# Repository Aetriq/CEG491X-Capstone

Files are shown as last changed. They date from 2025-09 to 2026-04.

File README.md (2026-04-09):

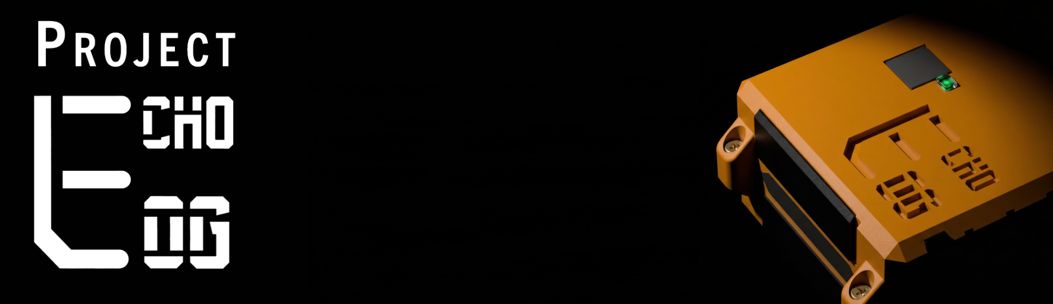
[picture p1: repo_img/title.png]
titlecard


<h1 align="center">Project EchoLog</h1>

<p align="center">
  CEG491X Capstone Project <br/>
  Faculty of Electrical and Computer Engineering @ University of Ottawa
  <br/>
  <br />

  <p align="center">
    
    &nbsp;
    
    &nbsp;
    
    &nbsp;
    
    &nbsp;
    
  <p align="center">

## Project Description
Based on the needs of our client, EchoLog is designed to be applicable with similar goals of recording and storing different forms of logs in high intensity/stress environments. It can also can provide value to any party from individuals that are spending out of pocket to improve their volunteering experience, to organizations with varying budgets. 

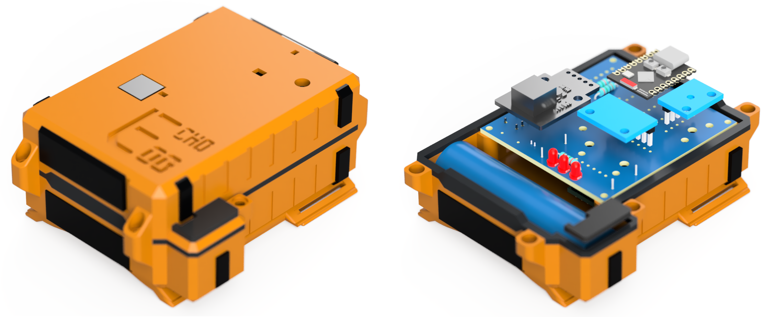
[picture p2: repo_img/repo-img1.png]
Concept Image Render

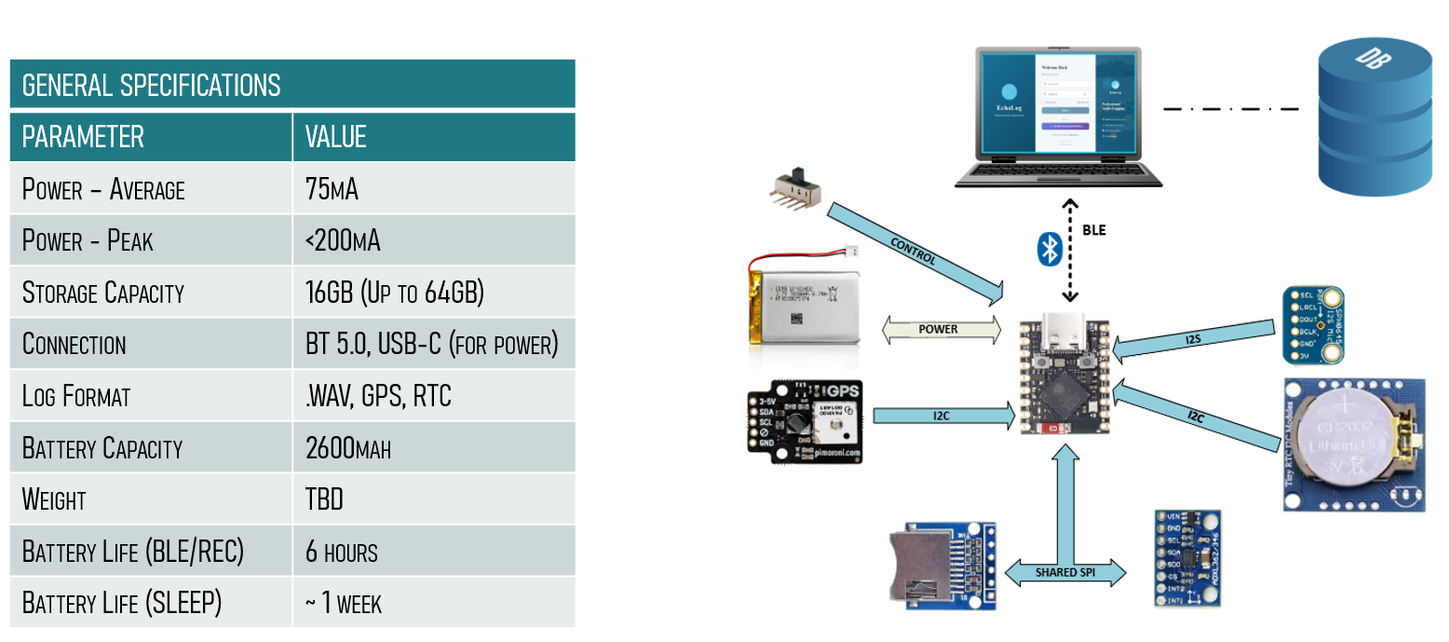
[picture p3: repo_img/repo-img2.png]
Specifications


## Development Images
<p align="center">
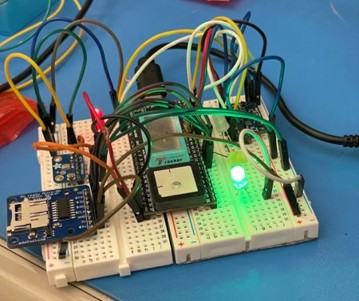
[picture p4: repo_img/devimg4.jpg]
devimg
  
</p>
<p align="center">
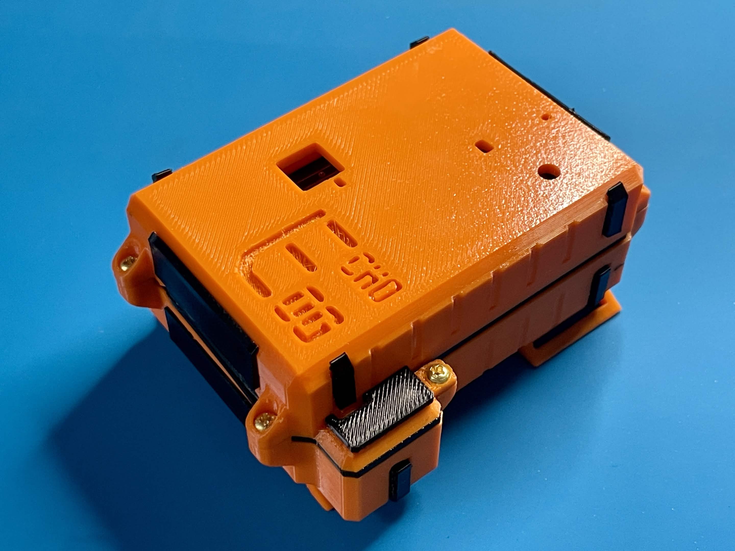
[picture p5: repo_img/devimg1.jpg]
devimg
  
</p>
<p align="center">
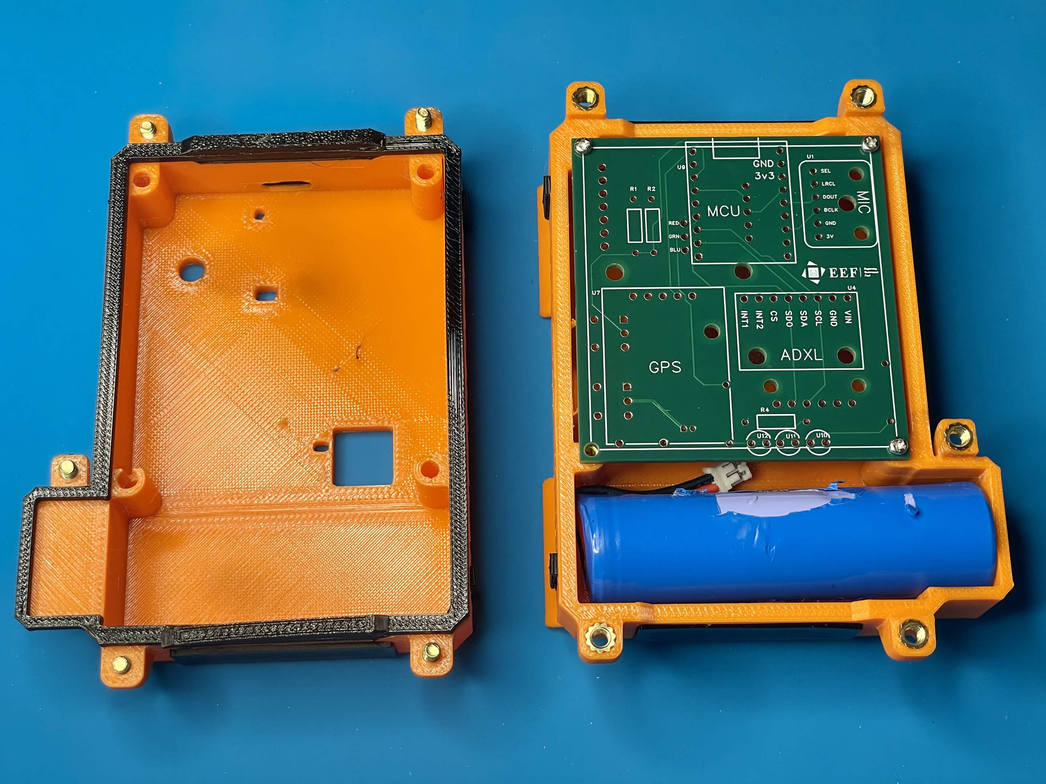
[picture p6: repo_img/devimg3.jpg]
devimg
  
</p>
<p align="center">
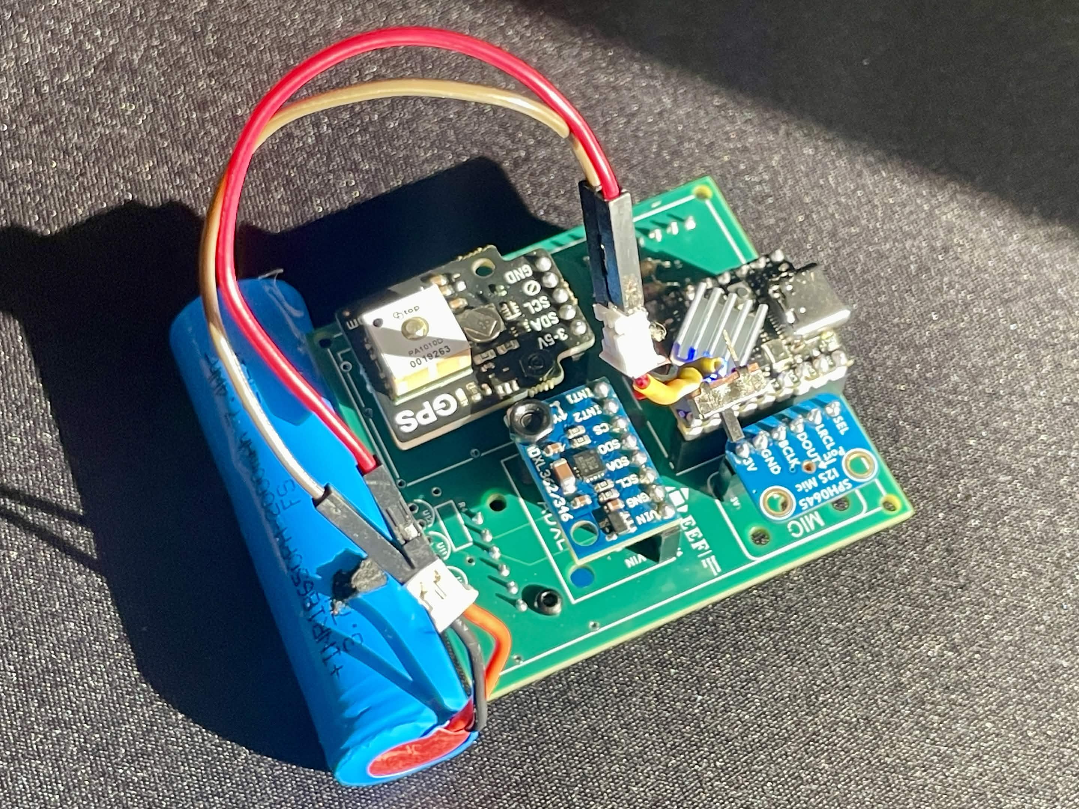
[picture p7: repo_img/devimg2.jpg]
devimg
  
</p>

---

## Features
- Fully handsfree operation & usage.
- Extremely low maitenance & high durability/physical protection.
- Rated for IP56 water/dust protection.
- Capable of sustaining external thermal loads up to 80C.
- Ultra low power, consuming <200mA peak, allowing for at least 8 hours of battery life. 
- Advanced gesture detection and fully autonomous recording of various formats, including audio and GPS.
- Dedicated app allows connection via USB-C serial and Bluetooth.

---

## Technologies Used
- **Frontend**: Angular, HTML, CSS.
- **Backend**: C, ESP-IDF Framework, Baremetal FreeRTOS
- **Image builder/flasher**: PlatformIO.

---
## Credits
- [Get your project supported with the the Engineering Endowment Fund (EEF)](https://www.uottawa.ca/faculty-engineering/student-hub/funding-student-initiatives)
- [ESP32-S3 by EspressIF](https://docs.espressif.com/projects/esp-idf/en/stable/esp32s3/)
- [EasyEDA](https://easyeda.com/)
- [AutoDesk Fusion](https://www.autodesk.com/products/fusion-360)

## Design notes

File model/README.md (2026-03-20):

<!-- PROJECT LOGO -->
<p align="center">
  <a href="https://github.com/Aetriq/CEG491X-Capstone">
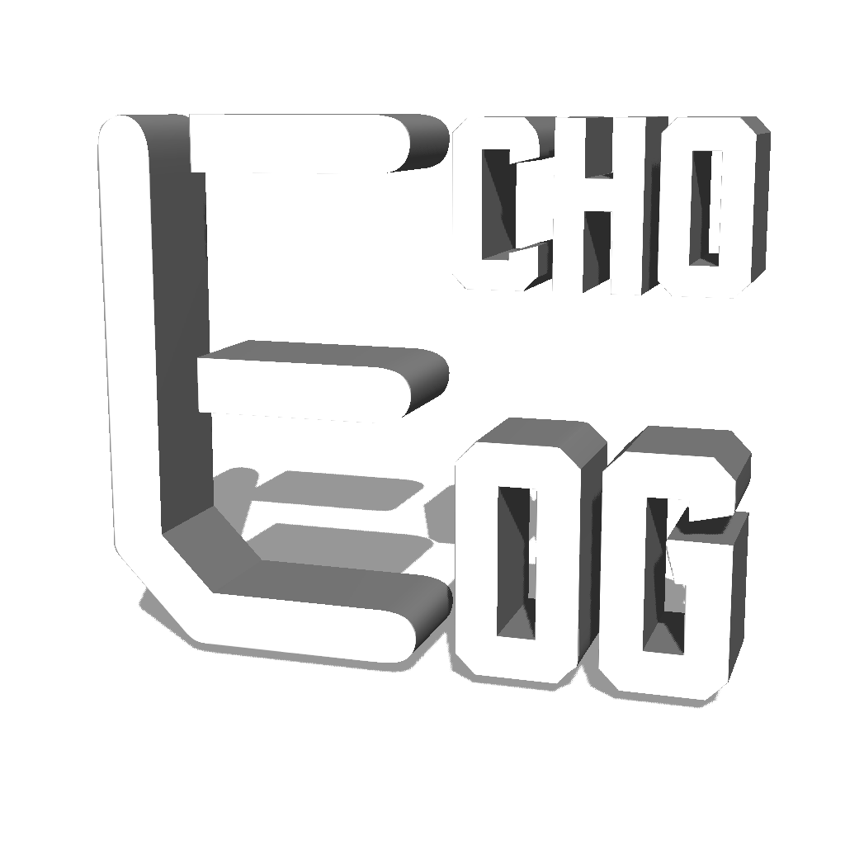
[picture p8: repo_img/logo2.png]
Project Logo
    
  </a>
</p>

<h1 align="center">Project EchoLog</h1>

<p align="center">
  CEG491X Capstone Project <br/>
  Faculty of Electrical and Computer Engineering @   University of Ottawa
  <br/>

  # Physical CAD Design for EchoLog 
<p align="center">
   
The following print settings are recommended and universal for all printers. All parts can be printed at once. This table uses the filament provided in the BOM (**Overture PETG**); other brands may vary in temperature. Warping may be eliminated by using a draft shield.

### Basic Printing Config

| Property | Ideal | Minimum |
| :--- | :--- | :--- |
| **Layer Height** | 0.15 – 0.2mm | 0.25 – 0.3mm |
| **Infill** | 35%, Gyroid | 10%, Gyroid |
| **Perimeter** | 5 | 3 |
| **Support** | Organic, build plate only | Snug, build plate only |
| **Speed** | 200 – 600mm/s | 25 – 100mm/s |
| **Temperature** | 240°C, 80°C bed | 230°C, 70°C bed |

---

The following advanced print settings are also recommended but limited to the **Overture PET-G** [filament](https://a.co/d/02w19UyD) for reference. These properties were found and adjusted using the demo unit printed the week prior. Analysis of the demo unit showed signs of **under-extrusion** at some points, which will severely compromise the IP rating. This has been taken into account in the following table and is universal to common modern printers.

### Advanced Printing Config

| Property | Value |
| :--- | :--- |
| **'Elephant's foot' Compensation** | 0.15mm |
| **Maximum Volumetric Speed** | 8mm^3/s |
| **Wall Generator** | Classic |
| **Infill overlap (Anchor)** | >30% |

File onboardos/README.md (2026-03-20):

<!-- PROJECT LOGO -->
<p align="center">
  <a href="https://github.com/Aetriq/CEG491X-Capstone">
    Project Logo
  </a>
</p>

<h1 align="center">Project EchoLog</h1>

<p align="center">
  CEG491X Capstone Project <br/>
  Faculty of Electrical and Computer Engineering @   University of Ottawa
  <br/>

  # Onboard Firmware for the ESP32-S3 Modules
<p align="center">
   
## Steps to Install
### Part 1: Setting up hardware
This is applicable to both the Heltec IOT Wireless Tracker v1.1 and the ESP32-S3 Supermini variants

#### Step 1: OS Support & Dependencies

Before you begin, ensure your system is prepared for serial communication

##### Supported Operating Systems
* **Windows 10/11:** Natively supported. Older versions may need CP210x or CH340 drivers
* **macOS:** High Sierra (>10.13) or newer. No additional drivers are usually required for the S3
* **Linux:** Ubuntu, Debian, Arch, etc.
    * Note: You may need to add your user to the dialout group: `sudo usermod -a -G dialout $USER`

##### Required Depedencies
1. Python >3.7:
2. Pip: 

#### Step 2: Install the Flashing Tool
[esptool.py](https://www.espressif.com/en/support/download/other-tools) is used, the official utility from Espressif. You may download the GUI version but the CLI is recommended. Open your Terminal/Command Prompt and run:

**pip install esptool**

To verify the installation, type esptool.py version

#### Step 3: Hardware Connection

1. Connect your ESP32-S3 to your computer using a **USB-C Data Cable**.
2. Identify your serial port.
    * **Windows:** Right-click Start > Device Manager > Ports (COM & LPT). Look for "USB Serial Port" or "ESP32-S3".
    * **macOS/Linux:** Run ls /dev/cu.* or ls /dev/ttyACM*.
3. Bootloader Mode (for Heltec Board): If the port doesn't appear, or the flash fails:
    * Press and hold the BOOT/USER button
    * Press the RESET (or RST) button once
    * Release the BOOT/USER button

#### Step 4: Flash the .bin File

Navigate to the folder containing your .bin file in your terminal. Use the command below, replacing PORT with your actual port (e.g. COM` or /dev/ttyACM0) and `your_file.bin` with your filename. For example,

**esptool.py --chip esp32s3 --port PORT --baud 921600 write_flash 0x0 FIRMWARE_2.0_HELTEC.bin**

#### Step 5: Reset and Verify

1. Once the terminal shows "Leaving... Hard resetting via RTS pin...", the process is finished.
2. Press the RESET button on the board to exit bootloader mode and run your program. IMPORTANT: DEVICE MUST BE IN DEEPSLEEP MODE WHEN PRESSING THE RST BUTTON!!!
3. (Optional) Open a Serial Monitor at 115200 baud to view the debug output.

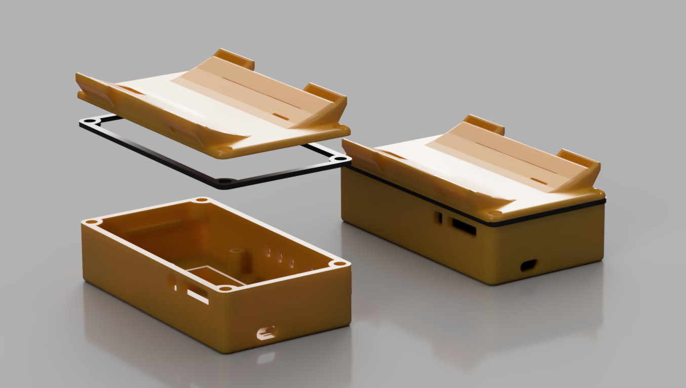
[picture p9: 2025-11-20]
model/Prototype 1 (v0.5)/render_2025-Nov-17_05-20-53PM-000_CustomizedView29221951694.png

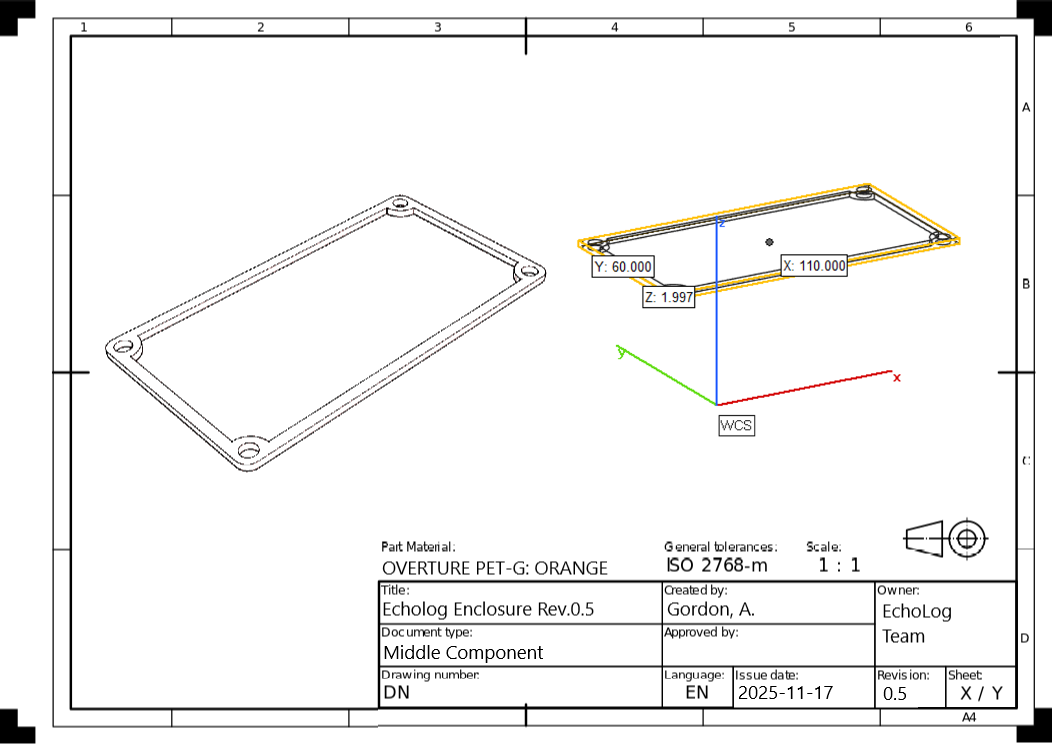
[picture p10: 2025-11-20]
model/Prototype 1 (v0.5)/Middle.png

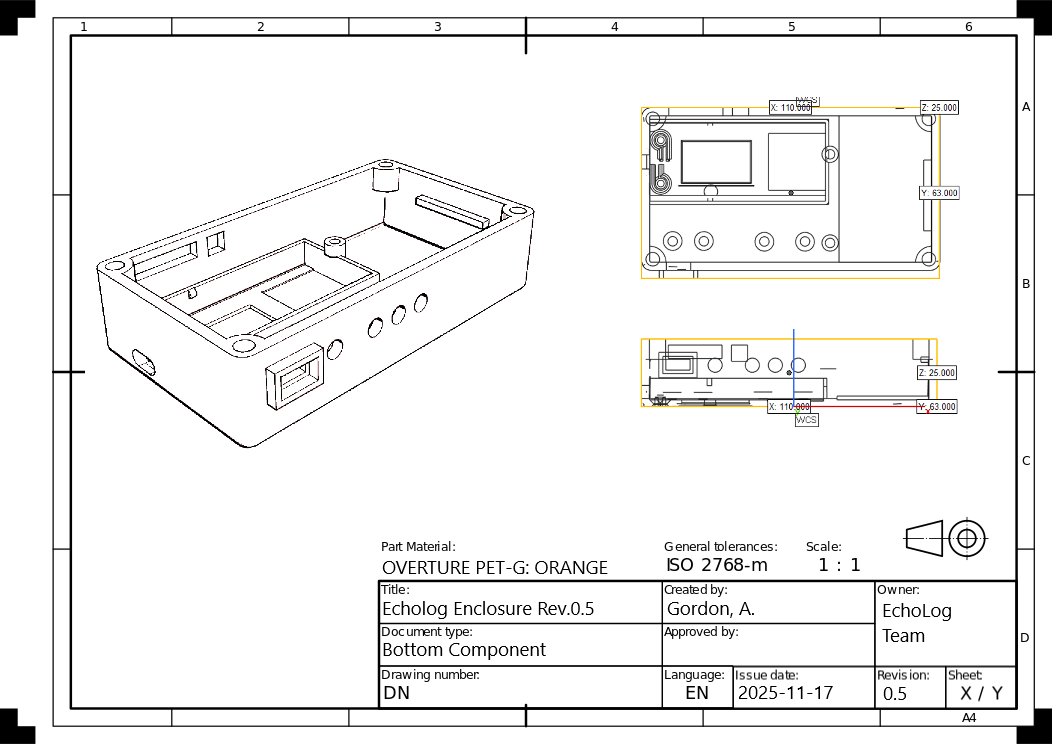
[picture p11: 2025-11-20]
model/Prototype 1 (v0.5)/Bottom.png

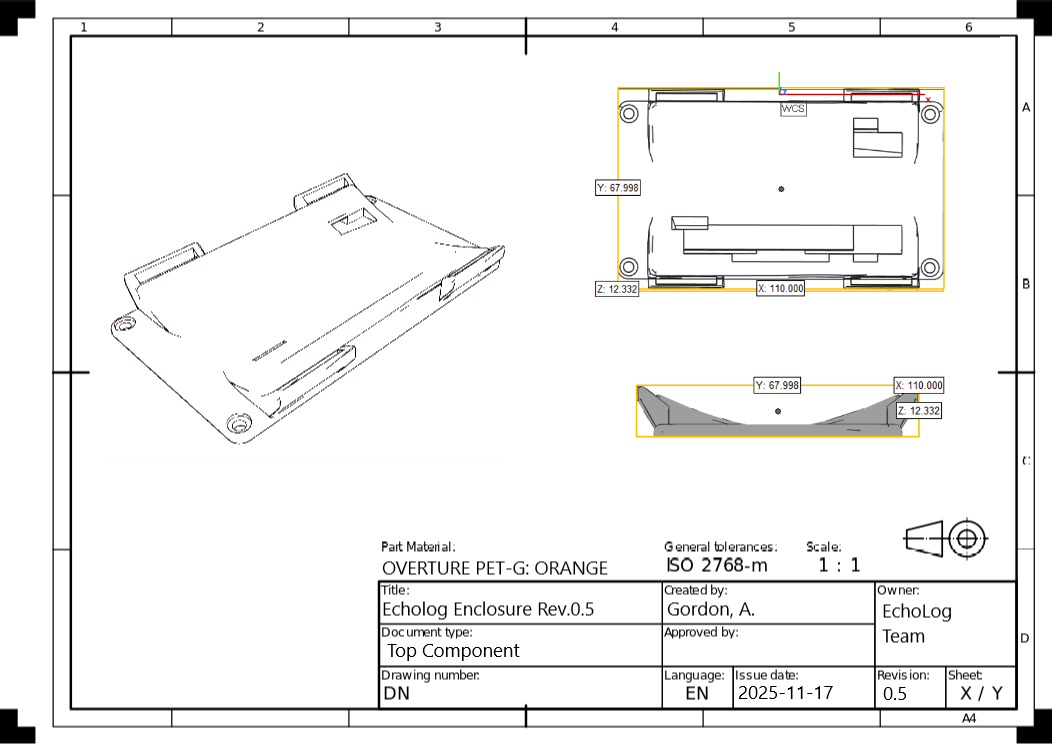
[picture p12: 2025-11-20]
model/Prototype 1 (v0.5)/Top.png

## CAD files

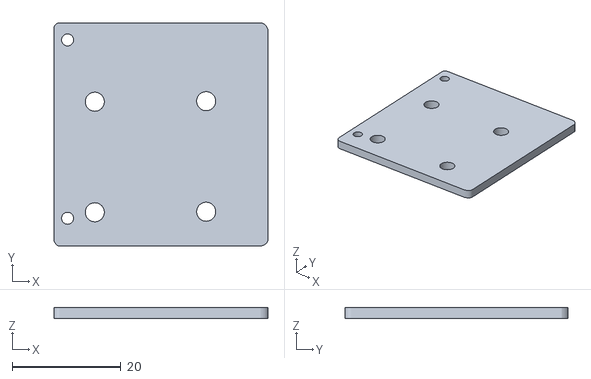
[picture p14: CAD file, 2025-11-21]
model/Prototype 1 (v0.5)/Middle Piece.stl
39.3 x 41.0 x 2.00

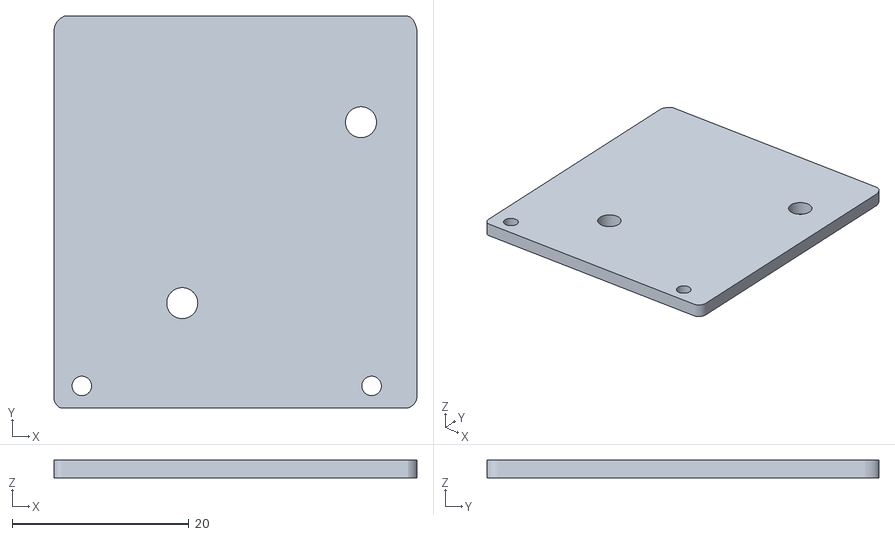
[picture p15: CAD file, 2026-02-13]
model/Prototype 2 (v0.8)/Middle Tray.obj
41.0 x 44.3 x 2.00

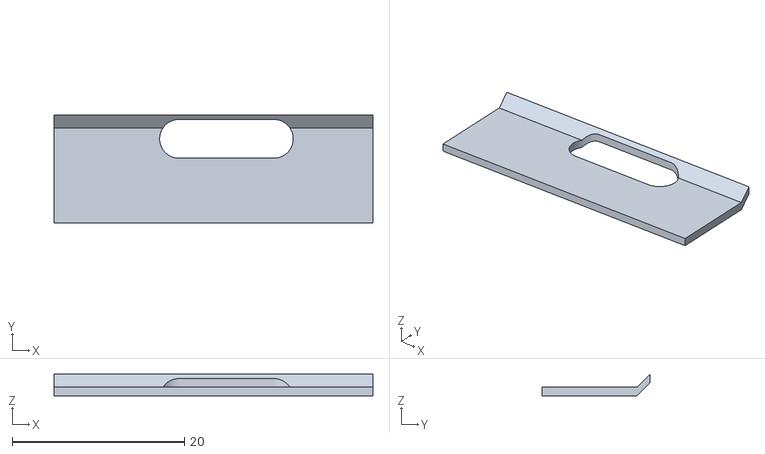
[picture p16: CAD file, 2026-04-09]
model/Prototype 3 (v1.0)/TPU Rear USB-C Bumper.stl
37.0 x 12.5 x 2.50

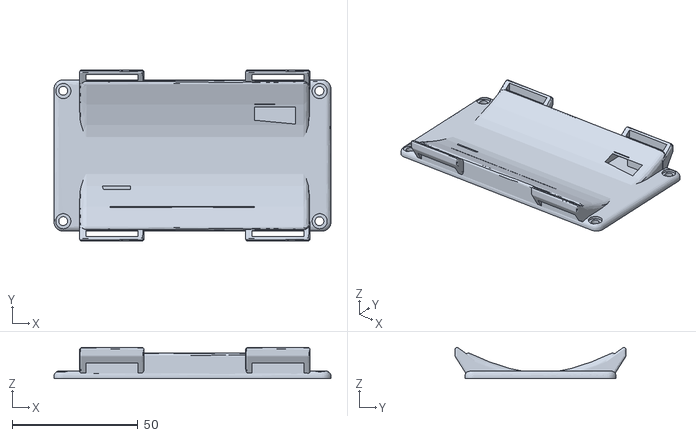
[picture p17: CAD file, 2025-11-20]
model/Prototype 1 (v0.5)/Top.stl
110.0 x 68.0 x 12.3

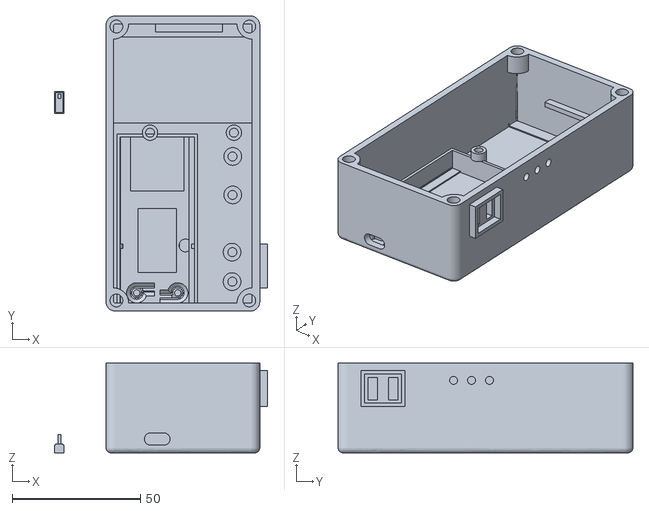
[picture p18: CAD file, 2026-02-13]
model/Prototype 2 (v0.8)/Bottom.obj
83.0 x 115.0 x 35.0

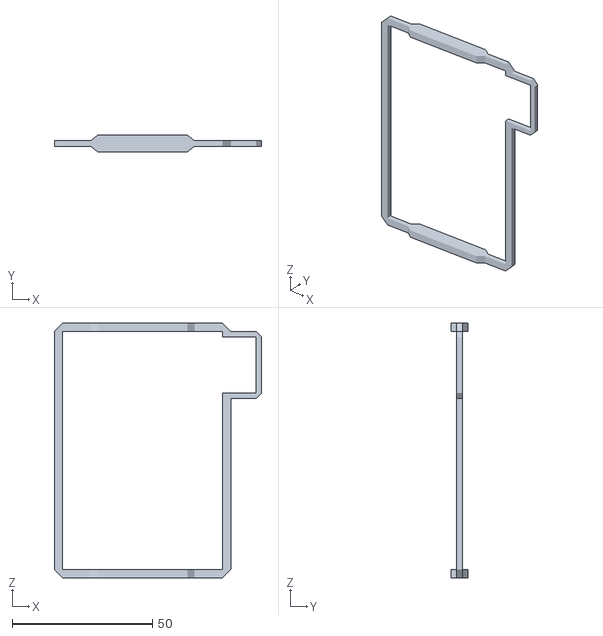
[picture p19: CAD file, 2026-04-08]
model/Prototype 3 (v1.0)/TPU Middle Gasket.stl
74.0 x 6.00 x 91.0

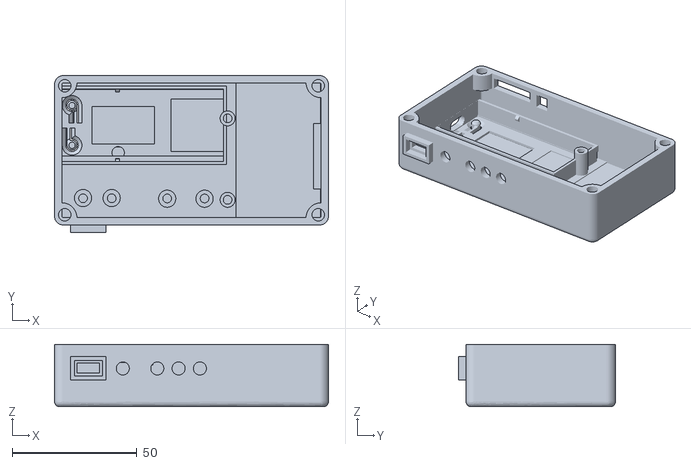
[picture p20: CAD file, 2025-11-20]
model/Prototype 1 (v0.5)/Bottom.stl
110.0 x 63.0 x 25.0

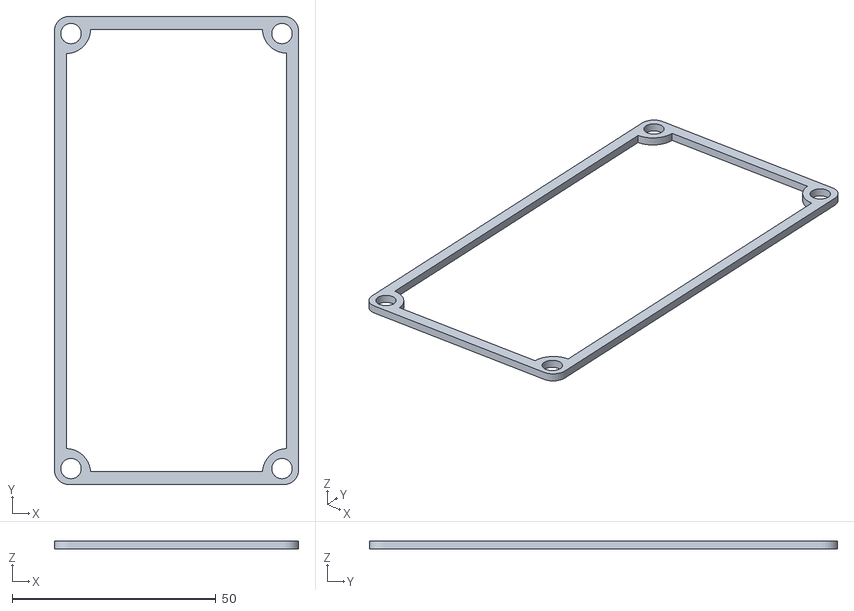
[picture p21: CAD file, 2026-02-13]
model/Prototype 2 (v0.8)/TPU Gasket.obj
60.0 x 114.9 x 2.00

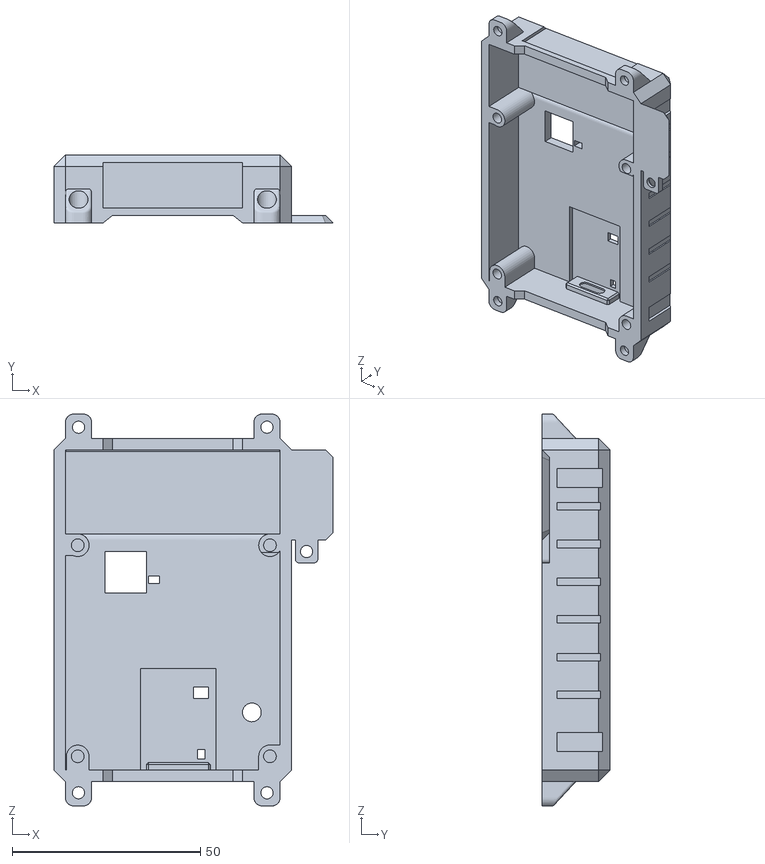
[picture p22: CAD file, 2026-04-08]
model/Prototype 3 (v1.0)/PETG Top Cover.stl
74.0 x 18.0 x 104.0

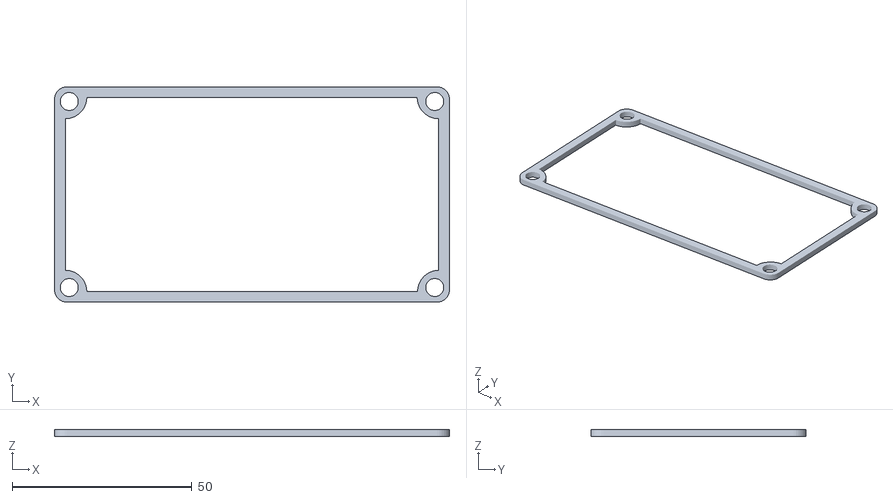
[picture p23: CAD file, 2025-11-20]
model/Prototype 1 (v0.5)/Middle Gasket.stl
110.0 x 60.0 x 2.00

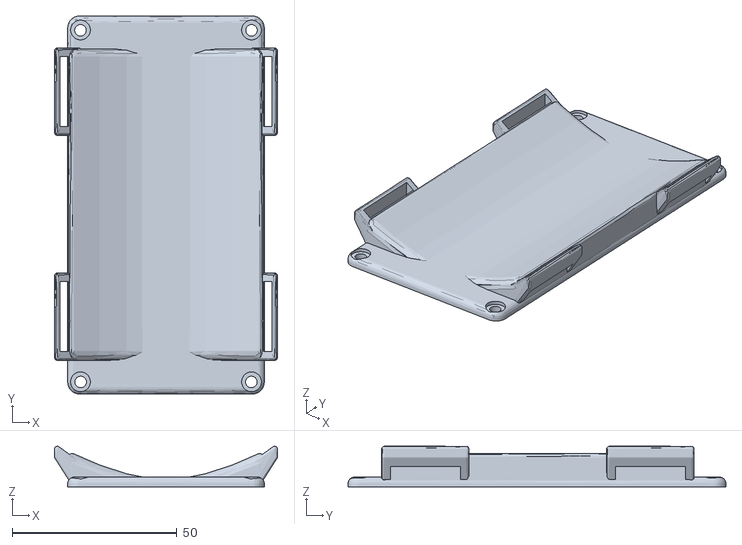
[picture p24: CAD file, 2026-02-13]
model/Prototype 2 (v0.8)/Top.obj
67.7 x 114.8 x 12.3

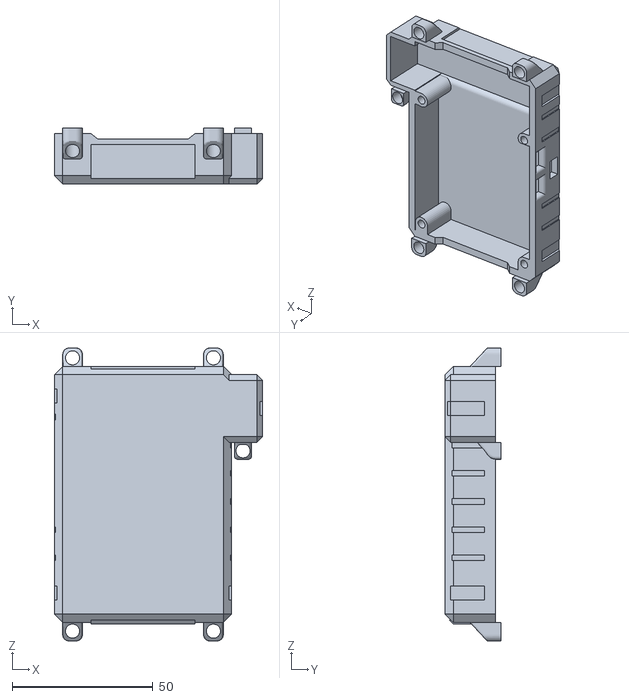
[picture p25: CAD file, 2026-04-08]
model/Prototype 3 (v1.0)/PETG Bottom Shell.stl
74.0 x 20.0 x 104.0

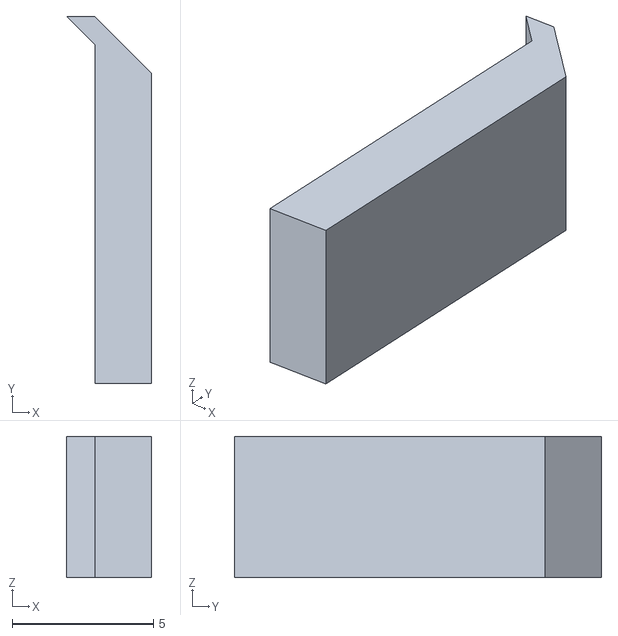
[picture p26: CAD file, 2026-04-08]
model/Prototype 3 (v1.0)/TPU Side Bumper .stl
3.00 x 13.0 x 5.00

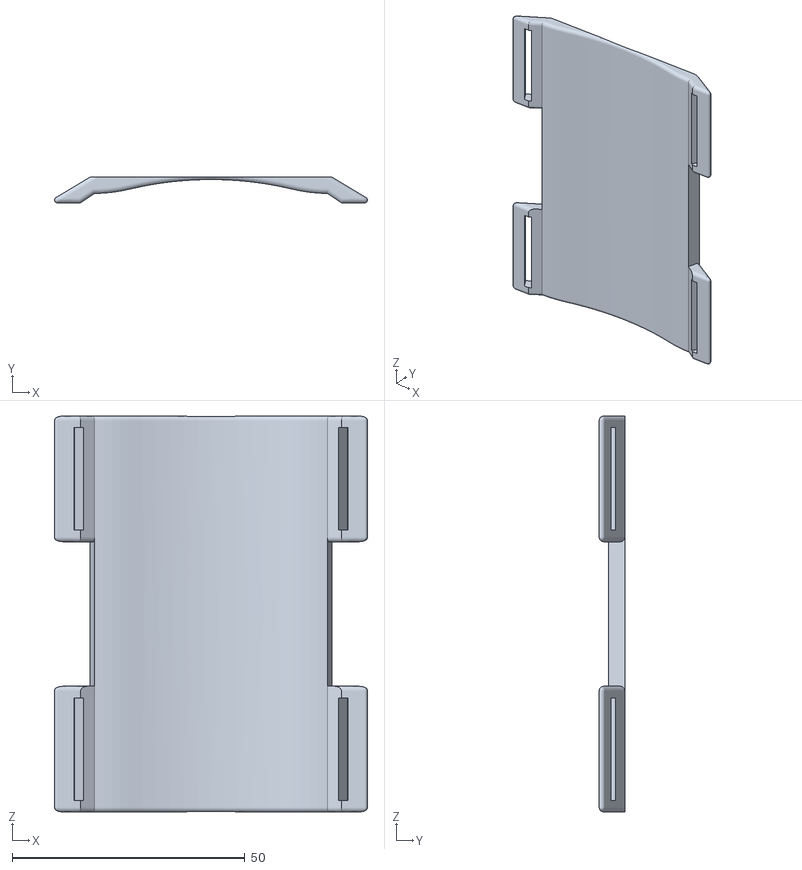
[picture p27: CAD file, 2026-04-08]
model/Prototype 3 (v1.0)/PETG Forearm Mount.stl
67.2 x 5.50 x 85.0

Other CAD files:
model/Prototype 3 (v1.0)/TPU Rear Bumper.stl
model/Prototype 3 (v1.0)/TPU Side Corner Bumper.stl
model/Prototype 3 (v1.0)/TPU Front Bumper.stl

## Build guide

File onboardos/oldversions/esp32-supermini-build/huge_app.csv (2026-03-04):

# Name | Type | SubType | Offset | Size | Flags
nvs | data | nvs | 0x9000 | 0x5000
phy_init | data | phy | 0xe000 | 0x1000
factory | app | factory | 0x10000 | 0x300000

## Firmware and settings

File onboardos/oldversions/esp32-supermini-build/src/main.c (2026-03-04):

/*
┌──────────────────────────────────────────────────────────────────────────────────────────────────────────────────────────────────┐
│    _______   ________  ___  ___  ________  ___       ________  ________          ________  _________  ________  ________         │
│   |\  ___ \ |\   ____\|\  \|\  \|\   __  \|\  \     |\   __  \|\   ____\        |\   __  \|\___   ___\\   __  \|\   ____\        │
│   \ \   __/|\ \  \___|\ \  \\\  \ \  \|\  \ \  \    \ \  \|\  \ \  \___|        \ \  \|\  \|___ \  \_\ \  \|\  \ \  \___|_       │
│    \ \  \_|/_\ \  \    \ \   __  \ \  \\\  \ \  \    \ \  \\\  \ \  \  ___       \ \   _  _\   \ \  \ \ \  \\\  \ \_____  \      │
│     \ \  \_|\ \ \  \____\ \  \ \  \ \  \\\  \ \  \____\ \  \\\  \ \  \|\  \       \ \  \\  \|   \ \  \ \ \  \\\  \|____|\  \     │
│      \ \_______\ \_______\ \__\ \__\ \_______\ \_______\ \_______\ \_______\       \ \__\\ _\    \ \__\ \ \_______\____\_\  \    │
│       \|_______|\|_______|\|__|\|__|\|_______|\|_______|\|_______|\|_______|        \|__|\|__|    \|__|  \|_______|\_________\   │
│                                                                                                                   \|_________|   │
└──────────────────────────────────────────────────────────────────────────────────────────────────────────────────────────────────┘
*/

/* Team EchoLog (Group 2) */
/* CEG4912/3 Capstone Project */
/* School of Electrical Engineering and Computer Science at the University of Ottawa */

/* Onboard OS for ESP32-S3 based SuperMini */
/* Main program to execute */

/* Author(s): Gordon, A., Spacek, A., Liu, M., Nyannak, D., Escalante, A. */
#include <stdio.h>
#include <stdlib.h>
#include <string.h>
#include <sys/unistd.h>
#include <sys/stat.h>
#include <sys/time.h>
#include <time.h>
#include <dirent.h>
#include "freertos/FreeRTOS.h"
#include "freertos/task.h"
#include "nvs_flash.h"
#include "esp_log.h"
#include "esp_bt.h"
#include "esp_gap_ble_api.h"
#include "esp_gatts_api.h"
#include "esp_bt_defs.h"
#include "esp_bt_main.h"
#include "esp_gatt_common_api.h"
#include "driver/gpio.h"
#include "driver/sdspi_host.h"
#include "driver/spi_common.h"
#include "esp_vfs_fat.h"
#include "sdmmc_cmd.h"
#include "led_strip.h"

#define SD_PIN_NUM_CS GPIO_NUM_7
#define SD_PIN_NUM_MOSI GPIO_NUM_6
#define SD_PIN_NUM_CLK GPIO_NUM_5
#define SD_PIN_NUM_MISO GPIO_NUM_4
#define RGB_LED_PIN GPIO_NUM_48
#define MOUNT_POINT "/sdcard"
#define TRANSFER_BLOCK_SIZE 490

static const char *TAG = "SUPERMINI_BLE_SD";
static const uint8_t service_uuid[16] = {0x4b,0x91,0x31,0xc3,0xc9,0xc5,0xcc,0x8f,0x9e,0x45,0xb5,0x1f,0x01,0xc2,0xaf,0x4f};
static const uint8_t char_cmd_uuid[16] = {0xa8,0x26,0x1b,0x36,0x07,0xea,0xf5,0xb7,0x88,0x46,0xe1,0x36,0x3e,0x48,0xb5,0xbe};
static const uint8_t char_data_uuid[16] = {0x3b,0x70,0x7c,0x68,0xb9,0x70,0x42,0x94,0x22,0x4c,0xc4,0x03,0x7c,0x28,0x9a,0x82};
static const uint8_t char_upload_uuid[16] = {0x0f,0x41,0xb3,0x04,0x10,0x00,0x20,0x81,0x03,0x49,0x83,0x58,0x12,0x1b,0x2e,0xce};
enum { IDX_SVC, IDX_CHAR_CMD, IDX_CHAR_VAL_CMD, IDX_CHAR_DATA, IDX_CHAR_VAL_DATA, IDX_CHAR_CFG_DATA, IDX_CHAR_UPLOAD, IDX_CHAR_VAL_UPLOAD, HRS_IDX_NB };

static uint16_t conn_id = 0, echo_handle_table[HRS_IDX_NB];
static esp_gatt_if_t gatts_if_handle = 0;
static bool device_connected = false, is_downloading = false, is_uploading = false, cmd_ready = false;
FILE *transfer_file = NULL;
char pending_cmd[128] = {0};
static sdmmc_card_t *card;
typedef enum { BLE_UNPAIRED, BLE_PAIRED, BLE_DISCONNECTED_BLINK } ble_led_state_t;
volatile ble_led_state_t current_ble_state = BLE_UNPAIRED;
led_strip_handle_t led_strip;

esp_err_t send_notification(uint8_t *data, size_t len) {
    if(device_connected) return esp_ble_gatts_send_indicate(gatts_if_handle, conn_id, echo_handle_table[IDX_CHAR_VAL_DATA], len, data, false);
    return ESP_FAIL;
}
void send_eof() { send_notification((uint8_t*)"EOF", 3); }

void mount_sd_ble() {
    esp_vfs_fat_sdmmc_mount_config_t mount_config = {.format_if_mount_failed=false, .max_files=5, .allocation_unit_size=16*1024};
    gpio_set_pull_mode(SD_PIN_NUM_MISO, GPIO_PULLUP_ONLY); gpio_set_pull_mode(SD_PIN_NUM_MOSI, GPIO_PULLUP_ONLY);
    gpio_set_pull_mode(SD_PIN_NUM_CLK, GPIO_PULLUP_ONLY); gpio_set_pull_mode(SD_PIN_NUM_CS, GPIO_PULLUP_ONLY);
    sdmmc_host_t host = SDSPI_HOST_DEFAULT(); host.slot = SPI2_HOST; host.max_freq_khz = 4000;
    spi_bus_config_t bus_cfg = {.mosi_io_num=SD_PIN_NUM_MOSI, .miso_io_num=SD_PIN_NUM_MISO, .sclk_io_num=SD_PIN_NUM_CLK, .quadwp_io_num=-1, .quadhd_io_num=-1, .max_transfer_sz=4000};
    spi_bus_initialize(host.slot, &bus_cfg, SPI_DMA_CH_AUTO);
    sdspi_device_config_t slot_config = SDSPI_DEVICE_CONFIG_DEFAULT(); slot_config.gpio_cs=SD_PIN_NUM_CS; slot_config.host_id=host.slot;
    if(esp_vfs_fat_sdspi_mount(MOUNT_POINT, &host, &slot_config, &mount_config, &card)==ESP_OK) ESP_LOGI(TAG, "SD Card mounted"); else ESP_LOGE(TAG, "Failed to mount SD card");
}

void rgb_led_task(void *pvParameters) {
    bool toggle = false;
    while(1) {
        switch(current_ble_state) {
            case BLE_UNPAIRED:
                led_strip_set_pixel(led_strip, 0, toggle?50:0, 0, toggle?0:50); led_strip_refresh(led_strip); toggle = !toggle; vTaskDelay(pdMS_TO_TICKS(500)); break;
            case BLE_PAIRED:
                led_strip_set_pixel(led_strip, 0, 0, 0, 50); led_strip_refresh(led_strip); vTaskDelay(pdMS_TO_TICKS(250)); break;
            case BLE_DISCONNECTED_BLINK:
                for(int i=0; i<2; i++) { led_strip_set_pixel(led_strip, 0, 100, 0, 0); led_strip_refresh(led_strip); vTaskDelay(pdMS_TO_TICKS(150)); led_strip_clear(led_strip); vTaskDelay(pdMS_TO_TICKS(150)); }
                current_ble_state = BLE_UNPAIRED; break;
        }
    }
}

void process_command_task(void *pvParameters) {
    uint8_t *fileBuf = malloc(TRANSFER_BLOCK_SIZE); char filepath[300];
    while(1) {
        if(cmd_ready) {
            if(!strcmp(pending_cmd, "ls")) { DIR *dir = opendir(MOUNT_POINT); if(dir) { struct dirent *entry; while((entry=readdir(dir))) { if(entry->d_type==DT_REG) { snprintf(filepath, sizeof(filepath), "%s/%s", MOUNT_POINT, entry->d_name); struct stat st; if(!stat(filepath, &st)) { char line[300]; int len=snprintf(line, sizeof(line), "%s|%ld", entry->d_name, st.st_size); send_notification((uint8_t*)line, len); vTaskDelay(pdMS_TO_TICKS(20)); } } } closedir(dir); } send_eof(); }
            else if(!strncmp(pending_cmd, "get ", 4)) { char *fname = pending_cmd+4; snprintf(filepath, sizeof(filepath), "%s/%s", MOUNT_POINT, (fname[0]=='/')?fname+1:fname); if(transfer_file) fclose(transfer_file); transfer_file = fopen(filepath, "rb"); if(transfer_file) is_downloading = true; else send_eof(); }
            else if(!strncmp(pending_cmd, "time ", 5)) { int y, m, d, hh, mm, ss; if(sscanf(pending_cmd+5, "%d %d %d %d %d %d", &y, &m, &d, &hh, &mm, &ss)==6) { struct tm tm_info = {.tm_year=y-1900, .tm_mon=m-1, .tm_mday=d, .tm_hour=hh, .tm_min=mm, .tm_sec=ss}; struct timeval now = {.tv_sec=mktime(&tm_info), .tv_usec=0}; settimeofday(&now, NULL); char reply[20]; int len=snprintf(reply, sizeof(reply), "SET:%04d%02d%02d", y, m, d); send_notification((uint8_t*)reply, len); } else send_notification((uint8_t*)"TIME_ERR", 8); send_eof(); }
            else if(!strncmp(pending_cmd, "upload ", 7)) { char *fname = pending_cmd+7; snprintf(filepath, sizeof(filepath), "%s/%s", MOUNT_POINT, (fname[0]=='/')?fname+1:fname); if(transfer_file) fclose(transfer_file); unlink(filepath); transfer_file = fopen(filepath, "wb"); if(transfer_file) { is_uploading = true; send_notification((uint8_t*)"READY", 5); } else send_notification((uint8_t*)"ERROR", 5); }
            else if(!strcmp(pending_cmd, "end_upload")) { if(transfer_file) { fclose(transfer_file); transfer_file = NULL; } is_uploading = false; send_eof(); }
            cmd_ready = false;
        }
        if(is_downloading && device_connected && transfer_file) {
            int len = fread(fileBuf, 1, TRANSFER_BLOCK_SIZE, transfer_file);
            if(len > 0) { esp_err_t err = send_notification(fileBuf, len); if(err == ESP_FAIL || err == ESP_ERR_NO_MEM) { fseek(transfer_file, -len, SEEK_CUR); vTaskDelay(1); } }
            else { fclose(transfer_file); transfer_file = NULL; is_downloading = false; send_eof(); }
        } else vTaskDelay(pdMS_TO_TICKS(10));
    }
}

static void gap_event_handler(esp_gap_ble_cb_event_t event, esp_ble_gap_cb_param_t *param) {
    if(event == ESP_GAP_BLE_ADV_DATA_SET_COMPLETE_EVT) esp_ble_gap_start_advertising(&(esp_ble_adv_params_t){.adv_int_min=0x20, .adv_int_max=0x40, .adv_type=ADV_TYPE_IND, .own_addr_type=BLE_ADDR_TYPE_PUBLIC, .channel_map=ADV_CHNL_ALL, .adv_filter_policy=ADV_FILTER_ALLOW_SCAN_ANY_CON_ANY});
}

static void gatts_event_handler(esp_gatts_cb_event_t event, esp_gatt_if_t gatts_if, esp_ble_gatts_cb_param_t *param) {
    switch(event) {
    case ESP_GATTS_REG_EVT: {
        gatts_if_handle = gatts_if; esp_ble_gap_set_device_name("SuperMini_SD");
        esp_ble_gap_config_adv_data(&(esp_ble_adv_data_t){.set_scan_rsp=false, .include_name=true, .include_txpower=false, .min_interval=0x0006, .max_interval=0x0010, .appearance=0x00, .manufacturer_len=0, .p_manufacturer_data=NULL, .service_data_len=0, .p_service_data=NULL, .service_uuid_len=16, .p_service_uuid=(uint8_t*)service_uuid, .flag=(ESP_BLE_ADV_FLAG_GEN_DISC|ESP_BLE_ADV_FLAG_BREDR_NOT_SPT)});
        static const uint16_t primary_service_uuid=ESP_GATT_UUID_PRI_SERVICE, character_declaration_uuid=ESP_GATT_UUID_CHAR_DECLARE, character_client_config_uuid=ESP_GATT_UUID_CHAR_CLIENT_CONFIG;
        static const uint8_t char_prop_write=ESP_GATT_CHAR_PROP_BIT_WRITE, char_prop_read_notify=ESP_GATT_CHAR_PROP_BIT_READ|ESP_GATT_CHAR_PROP_BIT_NOTIFY, ccc_value[2]={0x00, 0x00};
        const esp_gatts_attr_db_t gatt_db[HRS_IDX_NB] = {
            [IDX_SVC]={{ESP_GATT_AUTO_RSP},{ESP_UUID_LEN_16,(uint8_t*)&primary_service_uuid,ESP_GATT_PERM_READ,16,16,(uint8_t*)service_uuid}},
            [IDX_CHAR_CMD]={{ESP_GATT_AUTO_RSP},{ESP_UUID_LEN_16,(uint8_t*)&character_declaration_uuid,ESP_GATT_PERM_READ,1,1,(uint8_t*)&char_prop_write}},
            [IDX_CHAR_VAL_CMD]={{ESP_GATT_AUTO_RSP},{ESP_UUID_LEN_128,(uint8_t*)char_cmd_uuid,ESP_GATT_PERM_WRITE,200,0,NULL}},
            [IDX_CHAR_DATA]={{ESP_GATT_AUTO_RSP},{ESP_UUID_LEN_16,(uint8_t*)&character_declaration_uuid,ESP_GATT_PERM_READ,1,1,(uint8_t*)&char_prop_read_notify}},
            [IDX_CHAR_VAL_DATA]={{ESP_GATT_AUTO_RSP},{ESP_UUID_LEN_128,(uint8_t*)char_data_uuid,ESP_GATT_PERM_READ,200,0,NULL}},
            [IDX_CHAR_CFG_DATA]={{ESP_GATT_AUTO_RSP},{ESP_UUID_LEN_16,(uint8_t*)&character_client_config_uuid,ESP_GATT_PERM_READ|ESP_GATT_PERM_WRITE,2,2,(uint8_t*)ccc_value}},
            [IDX_CHAR_UPLOAD]={{ESP_GATT_AUTO_RSP},{ESP_UUID_LEN_16,(uint8_t*)&character_declaration_uuid,ESP_GATT_PERM_READ,1,1,(uint8_t*)&char_prop_write}},
            [IDX_CHAR_VAL_UPLOAD]={{ESP_GATT_AUTO_RSP},{ESP_UUID_LEN_128,(uint8_t*)char_upload_uuid,ESP_GATT_PERM_WRITE,512,0,NULL}},
        };
        esp_ble_gatts_create_attr_tab(gatt_db, gatts_if, HRS_IDX_NB, 0); break;
    }
    case ESP_GATTS_CREAT_ATTR_TAB_EVT:
        if(param->add_attr_tab.status==ESP_GATT_OK) { memcpy(echo_handle_table, param->add_attr_tab.handles, sizeof(echo_handle_table)); esp_ble_gatts_start_service(echo_handle_table[IDX_SVC]); } break;
    case ESP_GATTS_CONNECT_EVT: {
        conn_id=param->connect.conn_id; device_connected=true; current_ble_state=BLE_PAIRED;
        esp_ble_conn_update_params_t conn_params={0}; memcpy(conn_params.bda, param->connect.remote_bda, sizeof(esp_bd_addr_t)); conn_params.min_int=0x06; conn_params.max_int=0x0C; conn_params.latency=0; conn_params.timeout=400;
        esp_ble_gap_update_conn_params(&conn_params); esp_ble_gatt_set_local_mtu(517); break;
    }
    case ESP_GATTS_DISCONNECT_EVT:
        device_connected=false; is_downloading=false; current_ble_state=BLE_DISCONNECTED_BLINK;
        if(transfer_file) { fclose(transfer_file); transfer_file=NULL; }
        esp_ble_gap_start_advertising(&(esp_ble_adv_params_t){.adv_int_min=0x20, .adv_int_max=0x40, .adv_type=ADV_TYPE_IND, .own_addr_type=BLE_ADDR_TYPE_PUBLIC, .channel_map=ADV_CHNL_ALL, .adv_filter_policy=ADV_FILTER_ALLOW_SCAN_ANY_CON_ANY}); break;
    case ESP_GATTS_WRITE_EVT:
        if(param->write.handle==echo_handle_table[IDX_CHAR_VAL_CMD]) { int len=(param->write.len<sizeof(pending_cmd)-1)?param->write.len:sizeof(pending_cmd)-1; memcpy(pending_cmd, param->write.value, len); pending_cmd[len]=0; cmd_ready=true; }
        else if(param->write.handle==echo_handle_table[IDX_CHAR_VAL_UPLOAD]) { if(is_uploading&&transfer_file) fwrite(param->write.value, 1, param->write.len, transfer_file); }
        if(param->write.need_rsp) esp_ble_gatts_send_response(gatts_if, param->write.conn_id, param->write.trans_id, ESP_GATT_OK, NULL); 
        break;
    default: break;
    }
}

void app_main(void) {
    vTaskDelay(pdMS_TO_TICKS(3000));
    led_strip_config_t strip_config={.strip_gpio_num=RGB_LED_PIN, .max_leds=1}; led_strip_rmt_config_t rmt_config={.resolution_hz=10*1000*1000};
    ESP_ERROR_CHECK(led_strip_new_rmt_device(&strip_config, &rmt_config, &led_strip)); led_strip_clear(led_strip);
    esp_err_t ret=nvs_flash_init(); if(ret==ESP_ERR_NVS_NO_FREE_PAGES||ret==ESP_ERR_NVS_NEW_VERSION_FOUND) { ESP_ERROR_CHECK(nvs_flash_erase()); nvs_flash_init(); }
    mount_sd_ble();
    esp_bt_controller_config_t bt_cfg=BT_CONTROLLER_INIT_CONFIG_DEFAULT(); esp_bt_controller_init(&bt_cfg); esp_bt_controller_enable(ESP_BT_MODE_BLE); esp_bluedroid_init(); esp_bluedroid_enable();
    esp_ble_gatts_register_callback(gatts_event_handler); esp_ble_gap_register_callback(gap_event_handler); esp_ble_gatts_app_register(0);
    xTaskCreate(rgb_led_task, "rgb_task", 2048, NULL, 4, NULL); xTaskCreate(process_command_task, "sd_task", 4096*2, NULL, 5, NULL);
    while(1) vTaskDelay(pdMS_TO_TICKS(10000));
}

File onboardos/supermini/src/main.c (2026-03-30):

/*
┌──────────────────────────────────────────────────────────────────────────────────────────────────────────────────────────────────┐
│    _______   ________  ___  ___  ________  ___       ________  ________          ________  _________  ________  ________         │
│   |\  ___ \ |\   ____\|\  \|\  \|\   __  \|\  \     |\   __  \|\   ____\        |\   __  \|\___   ___\\   __  \|\   ____\        │
│   \ \   __/|\ \  \___|\ \  \\\  \ \  \|\  \ \  \    \ \  \|\  \ \  \___|        \ \  \|\  \|___ \  \_\ \  \|\  \ \  \___|_       │
│    \ \  \_|/_\ \  \    \ \   __  \ \  \\\  \ \  \    \ \  \\\  \ \  \  ___       \ \   _  _\   \ \  \ \ \  \\\  \ \_____  \      │
│     \ \  \_|\ \ \  \____\ \  \ \  \ \  \\\  \ \  \____\ \  \\\  \ \  \|\  \       \ \  \\  \|   \ \  \ \ \  \\\  \|____|\  \     │
│      \ \_______\ \_______\ \__\ \__\ \_______\ \_______\ \_______\ \_______\       \ \__\\ _\    \ \__\ \ \_______\____\_\  \    │
│       \|_______|\|_______|\|__|\|__|\|_______|\|_______|\|_______|\|_______|        \|__|\|__|    \|__|  \|_______|\_________\   │
│                                                                                                                   \|_________|   │
└──────────────────────────────────────────────────────────────────────────────────────────────────────────────────────────────────┘
*/

/* Team EchoLog (Group 2) */
/* CEG4912/3 Capstone Project */
/* School of Electrical Engineering and Computer Science at the University of Ottawa */

/* Onboard OS for ESP32-S3 based ESP-32 S3 Supermini */
/* Master Entry Point and Mode Switcher */

/* Author(s): Gordon, A., Spacek, A., Liu, M., Nyannak, D., Escalante, A. */

/* ========== TABLE OF CONTENTS ========== 
   1.0 Includes
   2.0 Variables & State Logic
   3.0 Persistent LED Task
   4.0 Main Application
========================================*/

/* ==================== 1.0 Includes ==================== */
#include "freertos/FreeRTOS.h"
#include "freertos/task.h"
#include "nvs_flash.h"
#include "esp_system.h"
#include "esp_sleep.h"
#include "esp_adc/adc_oneshot.h"
#include "globals.h"
#include "bluetooth_mode.h"
#include "recording_mode.h"
#include "gps_module.h"

/* ==================== 2.0 Variables & State Logic ==================== */
led_strip_handle_t led_strip;
volatile led_state_t sys_led_state = LED_IDLE;
adc_oneshot_unit_handle_t adc_handle;

system_mode_t get_system_mode(void) {
    int adc_raw = 0; adc_oneshot_read(adc_handle, ADC_CHANNEL_0, &adc_raw); // GPIO1 = ADC1_CH0
    if (adc_raw < 500) return MODE_SLEEP;
    if (adc_raw > 1600 && adc_raw < 2100) return MODE_BLUETOOTH; 
    if (adc_raw > 3500) return MODE_RECORDING; 
    return MODE_FLOATING;
}

/* ==================== 3.0 Persistent LED Task ==================== */
void persistent_led_task(void *pvParameters) {
    bool tog = false;
    while(1) {
        switch(sys_led_state) {
            case LED_IDLE: led_strip_clear(led_strip); led_strip_refresh(led_strip); vTaskDelay(pdMS_TO_TICKS(100)); break;
            case LED_BT_UNPAIRED: led_strip_set_pixel(led_strip, 0, tog?50:0, 0, tog?0:50); led_strip_refresh(led_strip); tog = !tog; vTaskDelay(pdMS_TO_TICKS(500)); break;
            case LED_BT_PAIRED: led_strip_set_pixel(led_strip, 0, 0, 0, 50); led_strip_refresh(led_strip); vTaskDelay(pdMS_TO_TICKS(250)); break;
            case LED_BT_DISCONNECTING: for(int i=0; i<2; i++) { led_strip_set_pixel(led_strip, 0, 50, 0, 0); led_strip_refresh(led_strip); vTaskDelay(pdMS_TO_TICKS(150)); led_strip_clear(led_strip); led_strip_refresh(led_strip); vTaskDelay(pdMS_TO_TICKS(150)); } sys_led_state = LED_BT_UNPAIRED; break;
            case LED_REC_IDLE: led_strip_set_pixel(led_strip, 0, 0, 50, 0); led_strip_refresh(led_strip); vTaskDelay(pdMS_TO_TICKS(250)); break;
            case LED_REC_STARTUP: led_strip_set_pixel(led_strip, 0, 50, 0, 0); led_strip_refresh(led_strip); vTaskDelay(pdMS_TO_TICKS(500)); led_strip_clear(led_strip); led_strip_refresh(led_strip); vTaskDelay(pdMS_TO_TICKS(500)); break;
            case LED_REC_ACTIVE: led_strip_set_pixel(led_strip, 0, 50, 0, 0); led_strip_refresh(led_strip); vTaskDelay(pdMS_TO_TICKS(250)); break;
            case LED_REC_ERROR: led_strip_set_pixel(led_strip, 0, 50, 50, 50); led_strip_refresh(led_strip); vTaskDelay(pdMS_TO_TICKS(1500)); sys_led_state = LED_REC_IDLE; break;
            case LED_SYS_FLOATING: led_strip_set_pixel(led_strip, 0, 50, 50, 50); led_strip_refresh(led_strip); vTaskDelay(pdMS_TO_TICKS(150)); led_strip_clear(led_strip); led_strip_refresh(led_strip); vTaskDelay(pdMS_TO_TICKS(150)); break;
            case LED_SELF_TEST: led_strip_set_pixel(led_strip, 0, 50, 0, 50); led_strip_refresh(led_strip); vTaskDelay(pdMS_TO_TICKS(250)); break;
        }
    }
}

/* ==================== 4.0 Main Application ==================== */
void app_main(void) {
    vTaskDelay(pdMS_TO_TICKS(1000));
    led_strip_config_t strip_config = {.strip_gpio_num = RGB_LED_PIN, .max_leds = 1}; 
    led_strip_rmt_config_t rmt_config = {.resolution_hz = 10 * 1000 * 1000};
    ESP_ERROR_CHECK(led_strip_new_rmt_device(&strip_config, &rmt_config, &led_strip)); led_strip_clear(led_strip);

    esp_err_t ret = nvs_flash_init(); 
    if(ret == ESP_ERR_NVS_NO_FREE_PAGES || ret == ESP_ERR_NVS_NEW_VERSION_FOUND) { ESP_ERROR_CHECK(nvs_flash_erase()); nvs_flash_init(); }

    adc_oneshot_unit_init_cfg_t init_config = { .unit_id = ADC_UNIT_1 }; ESP_ERROR_CHECK(adc_oneshot_new_unit(&init_config, &adc_handle));
    adc_oneshot_chan_cfg_t config = { .bitwidth = ADC_BITWIDTH_DEFAULT, .atten = ADC_ATTEN_DB_12 }; ESP_ERROR_CHECK(adc_oneshot_config_channel(adc_handle, ADC_CHANNEL_0, &config));

    if (get_system_mode() == MODE_SLEEP) { led_strip_clear(led_strip); led_strip_refresh(led_strip); gps_force_sleep(); esp_sleep_enable_timer_wakeup(500000); esp_deep_sleep_start(); }

    xTaskCreate(persistent_led_task, "sys_led", 2048, NULL, 5, NULL);

    while(1) {
        system_mode_t mode = get_system_mode();
        if (mode == MODE_BLUETOOTH) { sys_led_state = LED_BT_UNPAIRED; bluetooth_mode_main(); } 
        else if (mode == MODE_RECORDING) { sys_led_state = LED_REC_IDLE; recording_mode_main(); }
        else if (mode == MODE_FLOATING) { sys_led_state = LED_SYS_FLOATING; vTaskDelay(pdMS_TO_TICKS(250)); continue; }
        else if (mode == MODE_SLEEP) { sys_led_state = LED_IDLE; vTaskDelay(pdMS_TO_TICKS(100)); gps_force_sleep(); esp_sleep_enable_timer_wakeup(500000); esp_deep_sleep_start(); }
        
        sys_led_state = LED_IDLE; vTaskDelay(pdMS_TO_TICKS(500)); esp_restart();
    }
}

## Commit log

2025-10-24 Create accelerometer folder
2025-10-24 Create GreenYellowRed_accelerometer.ino
    added accelerometer test code. Written for ESP32 C6
2025-11-20 Add CAD Design and RTOS v0.5.0
    [Bottom.stl, Middl.stl, Top.stl]
2026-02-13 Prototype 2
    [Bottom.obj, Bottom.stl, Middle Gasket.stl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]
2026-03-04 Firmware v2.5 Features + DevTool
    [huge_app.csv]
2026-03-09 Completed RTOS for ESP32-S3 Supermini
    [huge_app.csv]
2026-03-20 Alot of updates (more firmware bugfixes)
    [globals.h, gps_module.c, recording_mode.c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]
2026-04-08 Add cad
    [PETG Bottom Shell.stl, PETG Forearm Mount.stl, PETG Top Cover.stl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]
2026-04-09 Repo improvements
    [TPU Rear USB-C Bumper.stl]
